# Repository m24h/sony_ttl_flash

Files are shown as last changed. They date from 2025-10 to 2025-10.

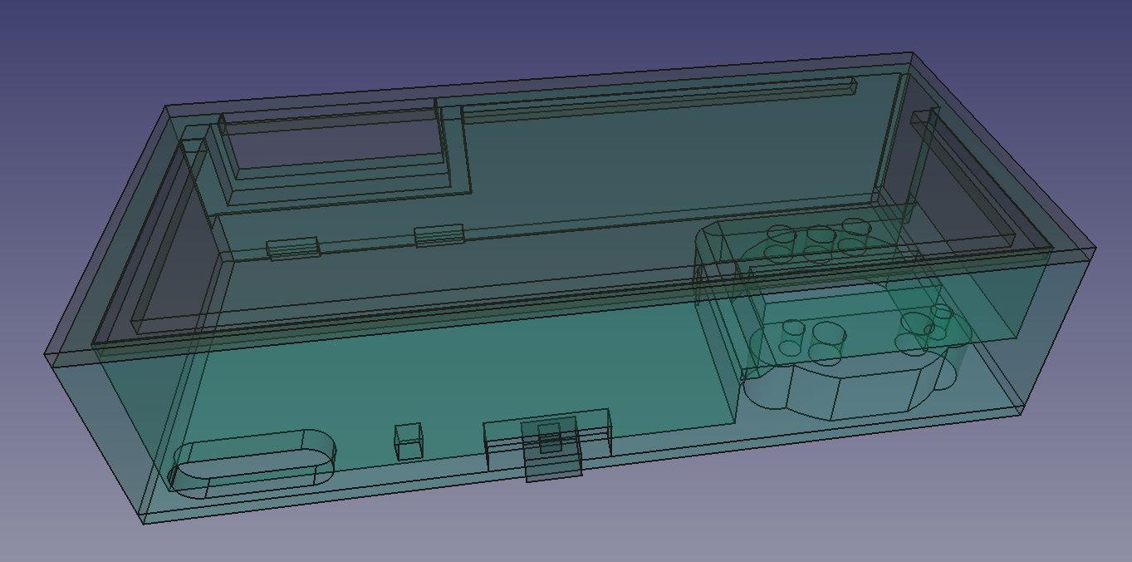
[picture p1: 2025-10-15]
parts/shell.png

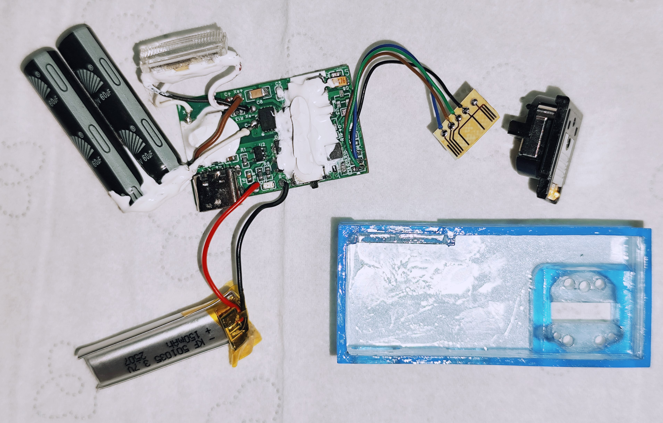
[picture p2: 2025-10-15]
practice/connection.jpg

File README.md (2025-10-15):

# sony_ttl_flash

A small Sony P-TTL flash

## Sony P-TTL and some details

Based on the discussion at [Discovering the flash protocol (long)](https://www.dyxum.com/dforum/topic8297.html), with some of my own research added, the camera will interact with the flash, reading the maximum flash power of the flash, indicating to the flash to fire at an appropriate energy. For specifics, see flash_sony.h.
FEL is not supported because I don't think it's needed, but if support is desired, flash.c needs to be modified, changing FLASH_SONY_READ_FEATURE_DEF to FLASH_SONY_READ_FEATURE_DEF | FLASH_SONY_READ_FEATURE_NEW, and it will increase the workload of communication (which can still be easily handled).
During macro photography, the camera's pre-flash seems too strong, which can lead to an underestimation of the flash level. Therefore, some corrections were made algorithmically, see FLASH_LOW_FLASH_ENHANCE in flash.h/flash.c.
The compiler is SDCC v4.5, and the compiled binary file is main.bin, designed based on STC8H1K08 (base on 8051, but MCU needs to support rising edge triggered interrupts), and the burning details refer to readme.txt and STC8H1K08.cfg.
The flash time of the level (flash_time_of_level in main.c) is specially calibrated for my actual xenon tube and capacitor, and may require recalibration on other tubes.
It's tested only on my A7CR camera.

## Pulseview

A sony flash protocol plug-in for pulseview is provided in directory pulseview. 

## Note and Issues

Frequent use of maximum power flash may damage IGBTs that do not have perfect cooling design.
The design is too small - but it's exactly what I need - the light will be blocked by a large lens, so I recommend using a small lens with a longer focal length.
The power switch is designed too small, making it inconvenient to operate. If necessary and there is extra space inside the casing, you could consider wiring it to a larger switch.

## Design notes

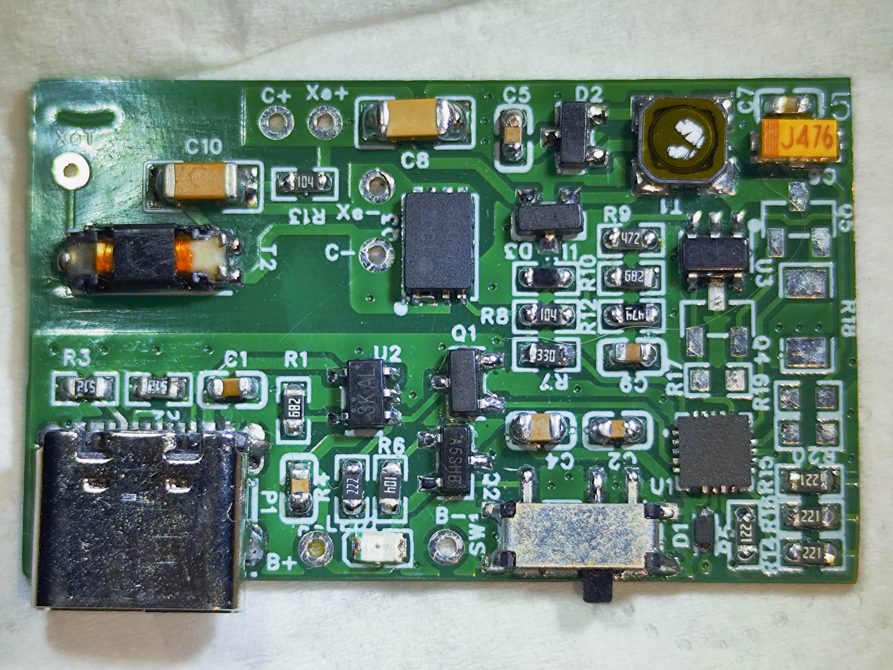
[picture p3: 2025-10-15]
practice/pcb_not_the_final.jpg

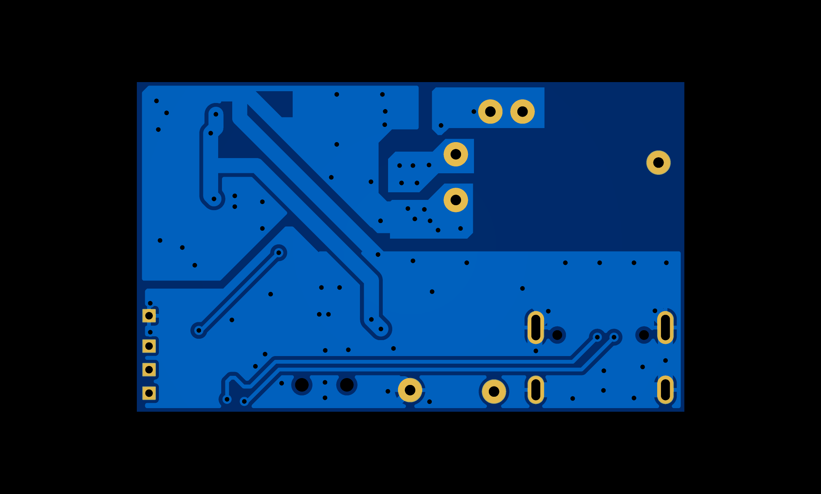
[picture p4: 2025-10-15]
circuit/pcb_bottom.png

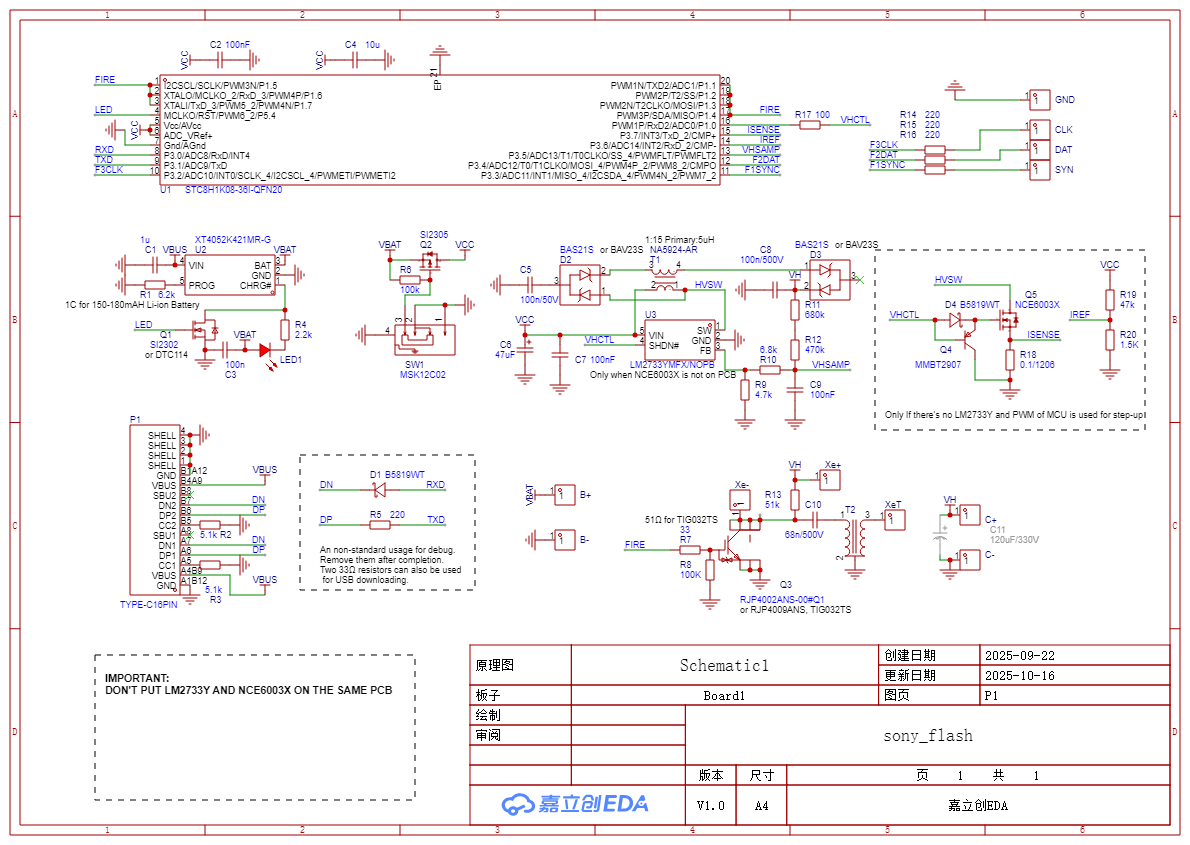
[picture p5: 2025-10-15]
circuit/sch.png

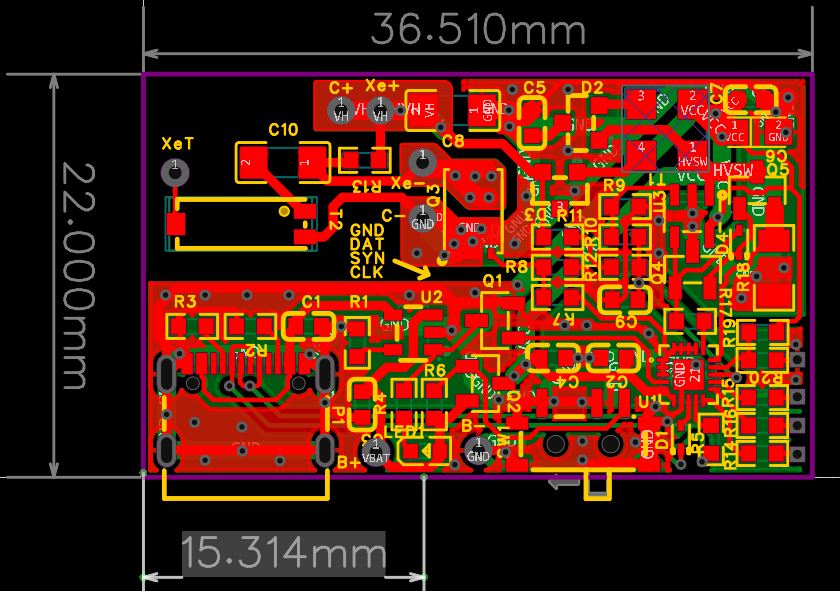
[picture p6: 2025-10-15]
circuit/pcb_size.png

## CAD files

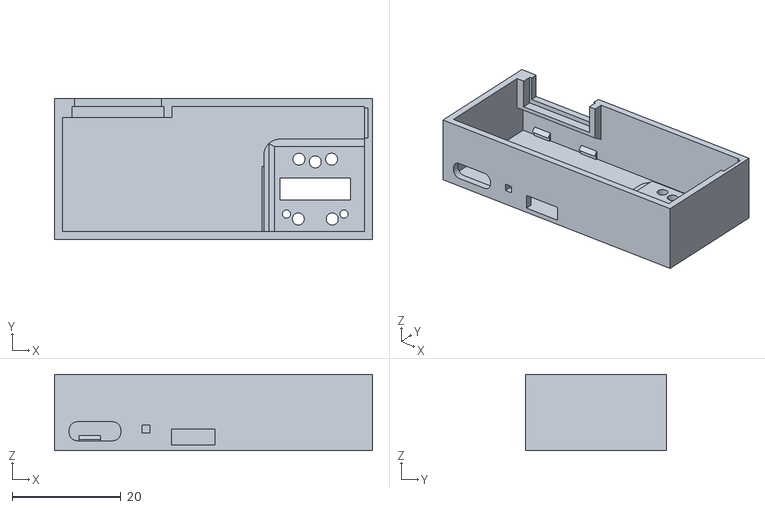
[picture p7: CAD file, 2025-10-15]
parts/shell-Body.stl
58.5 x 26.0 x 14.0

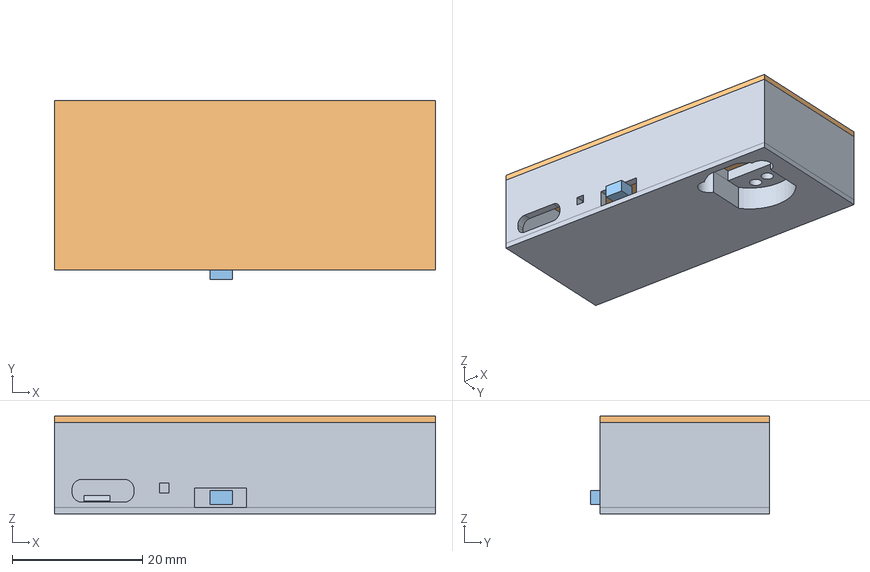
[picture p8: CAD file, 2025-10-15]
parts/shell.FCStd
58.5 x 27.5 x 15.0 mm
lid
knob

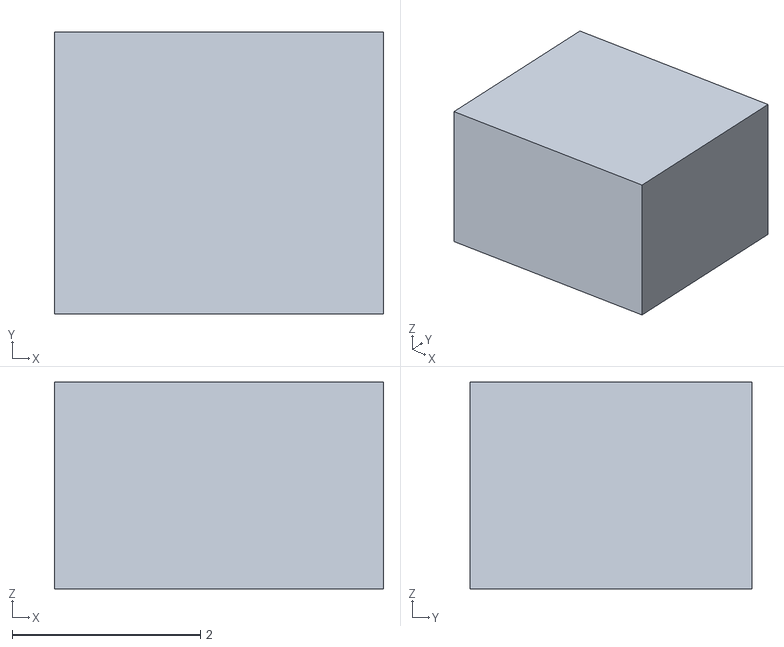
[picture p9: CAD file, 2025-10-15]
parts/shell-knob.stl
3.50 x 3.00 x 2.20

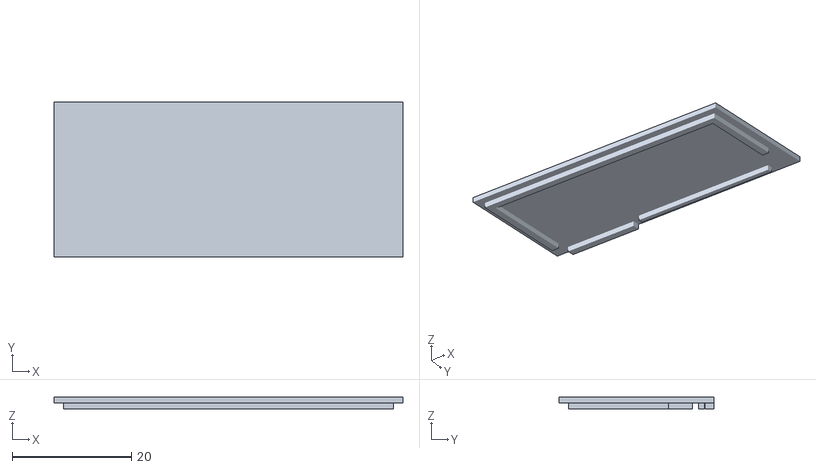
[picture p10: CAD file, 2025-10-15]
parts/shell-lid.stl
58.5 x 26.0 x 2.00

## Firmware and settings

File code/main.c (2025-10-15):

#include "main.h"

#include "stc/mem.h"
#include "stc/pio.h"
#include "stc/tmr.h"
#include "stc/sys.h"
#include "stc/ser.h"
#include "stc/adc.h"
#include "flash.h"

/*
this is a small flash with small Xenon tube and capacitor (GN6), 
so uses nearly a 1/4 full power (at flash_time_of_level[0]) as base/pre-flash power.
this table needs to be recalibrated after changing the Xenon tube and capacitor models. 
*/
const uint16_t flash_time_of_level[64] = {
52,61,72,87,104,126,151,183,
318,318,318,318,318,318,318,318,
318,318,318,318,318,318,318,318,
318,318,318,318,318,318,318,318,
12,12,12,12,12,12,13,14,
14,14,14,15,15,15,15,16,
17,18,19,19,20,21,21,22,
24,26,28,30,33,37,41,47
};


uint16_t volt_vdd_mv = 4000;
uint16_t volt_high = 0;

// ADC ref voltage, normally 1190mV
static uint16_t adc_ref=1190;

static __bit HV_disable = 0;
static __bit HV_on = 0;

#pragma save
#pragma disable_warning 126 // unreachable code by some setup macros
static void setup(void)
{
    sys_wdt_enable(1000, 0);
            
    // set ports (pins connected to camera are excluded)
    pio_disable_all();
    pio_reset(0);   // not to use reset pin
    pio_mclk(0, 0); // not to output sys clock
    VHSAMP=0;  pio_config(pio_pnn(VHSAMP), PIO_ANALOG); // VHSAMP
    RXD=1;     pio_config(pio_pnn(RXD), PIO_BIDIR | PIO_SCHMITT); 
    TXD=1;     pio_config(pio_pnn(TXD), PIO_BIDIR | PIO_SCHMITT); 
    LED=0;     pio_config(pio_pnn(LED), PIO_OUTPUT);
    P11=0;     pio_config(pio_pnn(P11), PIO_OUTPUT | PIO_STRONG | PIO_FAST); // to drive IGBT
    P12=0;     pio_config(pio_pnn(P12), PIO_OUTPUT | PIO_STRONG | PIO_FAST); // to drive IGBT
    P13=0;     pio_config(pio_pnn(P13), PIO_OUTPUT | PIO_STRONG | PIO_FAST); // to drive IGBT
    P14=0;     pio_config(pio_pnn(P14), PIO_OUTPUT | PIO_STRONG | PIO_FAST); // to drive IGBT
    P15=0;     pio_config(pio_pnn(P15), PIO_OUTPUT | PIO_STRONG | PIO_FAST); // to drive IGBT
    P16=0;     pio_config(pio_pnn(P16), PIO_OUTPUT | PIO_STRONG | PIO_FAST); // to drive IGBT
    P17=0;     pio_config(pio_pnn(P17), PIO_OUTPUT | PIO_STRONG | PIO_FAST); // to drive IGBT
    VHCTL=0;   pio_config(pio_pnn(VHCTL), PIO_OUTPUT | PIO_STRONG | PIO_FAST); // maybe needs to drive MOS

    // serial port 1 as debug port
    ser1_setup(BAUDRATE, 1, SER1_P30P31, 0); // use timer 1 to drive it, not to use intr.
    debug(1, "Starting\n");
        
    // LVD level
    sys_lvd_setup(3000, 0, 0);
    
    // timer 2 ticks every 10ms, started, will raise intr.
    tmr2_setup_reload24(100, 1, 1, 0, 0);

    // setup ADC
    adc_setup(ADC_RATE, 0, 0); // not to raise intr.
    debug(1, "ADC Rate = %u kHz\n", (uint16_t)(adc_real_speed(ADC_RATE)/1000));
#ifdef ADC_REF_MV
    adc_ref = ADC_REF_MV;
#else
    adc_ref = adc_ref_mv();
    if (adc_ref<1000 || adc_ref>1300) adc_ref=1190; // maybe VRef is not writen into ROM, so use the default
#endif
    debug(1, "ADC Ref = %u mV\n", adc_ref);
    
#ifdef USE_PWM_STEP_UP
    CMPCR2 = DISFLT; // not inv., no filter
    CMPEXCFG = 0;
    CMPCR1 = CMPEN | 0x04; // enable and use P36 as negative input
    PWMA_CCER1 = 0x00; // disable output for setting up
    PWMA_CR1 = 0x80; // ARR pre-load, stopped for setting up
    PWMA_CR2 = 0; 
    PWMA_RCR = 0;
    PWMA_IER = 0; // no intr. used
    PWMA_CCMR1 = 0x68; // PWM mode1, CCR pre-load
#if FOSC<20000000
#error PWM algorithm only work in at least 20MHz
#endif
    PWMA_PSCRH = 0;  // no clock pre-scale 
    PWMA_PSCRL = 0;
    PWMA_CNTRH = 0;
    PWMA_CNTRL = 0;
    PWMA_CCR1H = (uint16_t)(1.5476e-6*FOSC)>>8 ; // 4.2V, 5uH, 1.5476us -> 1.3A
    PWMA_CCR1L = (uint8_t)(uint16_t)(1.5476e-6*FOSC);
    PWMA_ARRH = 0xFF; // initialized maximum period
    PWMA_ARRL = 0xFF;
    PWMA_BKR = 0x3C; // MOE=0, AOE=0, BKP=1, BKE=1, OSSR=1, OSSI=1
    PWMA_OISR = 0; // idle state: OC1=0
    PWMA_PS = 0; // PWM1P in P10 
    PWMA_ETRPS = 0x07; // use comparator output as BRK
    PWMA_IOAUX = 0; 
    PWMA_ENO = 0x01; // enable PWM1P output
    PWMA_CCER1 = 0x01; // enable CC1P
    PWMA_CR1 |= 0x01; // start 
#endif    
}
#pragma restore

// timer 2 as system tick
static __data volatile uint16_t tick_10ms_isr = 0;
void tmr2_isr(void) __interrupt (TMR2_VECTOR) __naked
{
    // _tick_10ms_isr++
    __asm
    push    acc
    push    psw
    inc _tick_10ms_isr
    clr a
    cjne a, _tick_10ms_isr, 00010$
    inc (_tick_10ms_isr + 1)
00010$:
    pop psw
    pop acc
    reti
    __endasm;
}

uint16_t main_tick_get(void) __naked
{
    __asm
    anl _IE2, #(~ET2)
    nop
    nop
    mov dpl, (_tick_10ms_isr)
    mov dph, (_tick_10ms_isr+1)
    orl _IE2, #(ET2)
    ret
    __endasm;
}

static void shutdown(void)
{
    FLASH_STOP;
    HV_on = 0; // turn off high voltage
#ifdef USE_PWM_STEP_UP
    PWMA_BKR &= ~0xC0; // MOE=AOE=0 
#else
    VHCTL = 0;  
#endif    
    
    LED=0;
    sys_delay_ms(50);
}

// main entry
void main(void)
{
    
    EA = 0;
    nop();
    nop();
    mem_xram_enable();
    setup();
    flash_setup();
    EA = 1;
    
    // main loop
    while(1) {
        // feed the dog
        sys_wdt_clear();
        
        static uint16_t loops=0;
        ++loops;

        // power control
        if (PCON & LVDF || volt_vdd_mv<3200 || HV_disable) {
            HV_on = 0;
        } else if (volt_high<(uint16_t)(VH_DEST)-5) {
            HV_on = 1;
        } else if (volt_high>(uint16_t)(VH_DEST)+5) {
            HV_on = 0;
        }
        
#ifdef USE_PWM_STEP_UP
        if (HV_on) PWMA_BKR |= 0xC0; // MOE=AOE=1
        else PWMA_BKR &= ~0xC0; // MOE=AOE=0
#else
        VHCTL = HV_on;  
#endif    

        //To speed up the cycle turnaround, the tasks are spreaded using task number, which should be at 1-255
        static __data uint8_t taskno = 0;
        ++taskno;
        if (taskno == 1) { // get device voltages
            uint16_t t16 = adc_get(ADC_VREF_CH);
            t16 = adc_get(ADC_VREF_CH); // double get to avoid cross-interference
            if (t16<=4096) t16 = adc_get(ADC_VREF_CH);
            if (t16<=256) continue; // sometimes get 0, seems to be the "zero value" bug of STC ADC, many have encountered it too
            // adc_value/65536*Vdd = adc_ref
            // Vdd = adc_ref * 65536 / adc_value
            t16 = (uint16_t)((((uint32_t)adc_ref<<16)+(t16>>1))/t16);
            t16 = ((volt_vdd_mv<<1)+volt_vdd_mv+t16+2)>>2; // a simple filter
            EA = 0; // guarantee actomic data
            nop();
            nop();
            volt_vdd_mv=t16;
            EA = 1;
        } else if (taskno == 2) { // get high voltage
            uint16_t t16 = adc_get(ADC_VHSAMP_CH);
            t16 = adc_get(ADC_VHSAMP_CH); // double get to avoid cross-interference
            if (t16<=4096) t16 = adc_get(ADC_VHSAMP_CH);
            if (t16<=256) continue; // sometimes get 0 or noises, seems to be the "zero value" bug of STC ADC, many have encountered it too
            // adc_value/65536*volt_vdd_mv/1000 = volt_high*VH_RATIO+VH_BIAS
            // volt_high = (adc_value/65536*volt_vdd_mv/1000 - VH_BIAS)/VH_RATIO
            // volt_high = (1049*(adc_value/64)*volt_vdd_mv/65536 - VH_BIAS*16384)*(4/VH_RATIO)/65536
            t16 = (1049UL*volt_vdd_mv*(t16>>6)+32768)>>16;
            t16 = t16>(uint32_t)(VH_BIAS*16384) ? ((t16-(uint32_t)(VH_BIAS*16384))*(uint32_t)(4/VH_RATIO)+32768)>>16 : 0;
            t16 = ((volt_high<<1)+volt_high+t16+2)>>2; // a simple filter
            EA = 0; // guarantee actomic data
            nop();
            nop();
            volt_high = t16;
            EA = 1;
#ifdef USE_PWM_STEP_UP
            if (volt_high<=2) {
                PWMA_ARRH = 0xFF;
                PWMA_ARRL = 0xFF;            
            } else {
                uint16_t toff=(uint16_t)(0.08125*0.00128*FOSC)/(volt_high-2)+(uint16_t)(1.5476e-6*FOSC)+2; // 1.3/(15+1)=81.25mA, 5*(15+1)^2=1.28mH
                PWMA_ARRH = toff>>8;
                PWMA_ARRL = (uint8_t)toff;
            }
#endif
        } else if (taskno == 3) { // show LED
            if (volt_high<(uint16_t)(VH_LEAST)) {
                flash_can_fire = 0;
                if (HV_on) {
                    LED = (uint8_t)main_tick_get() & 0x10;
                } else {
                    LED = 1;
                }
            } else {
            	flash_can_fire = 1;
                LED = 1;
            } 
        } else if (taskno == 4) {
            // incoming message (1 byte only) from default serial port
            switch ((unsigned char)tolower(getchar())) {
                case 'b': printf("SP = %x, ticks = %u, loops=%u\n", SP, main_tick_get(), loops);
                          break;
                case 'd': shutdown();
                          pio_disable_all(); 
                          sys_boot_ISP();
                          break;
                case 'r': shutdown();
                          pio_disable_all();
                          sys_boot();
                          break;
                case 'a': printf("VH = %u, VDD = %u mV, VH = %u V\n", HV_on, volt_vdd_mv, volt_high);
                          break;
                case 'p': printf("VH = %u, LVD=%u, LED = %u\n", HV_on, (PCON & LVDF)?1:0, LED);
                          printf("F1SYNC = %u, F2DAT = %u, F3CLK = %u\n", FLASH_F1SYNC, FLASH_F2DAT, FLASH_F3CLK);
                          break;
                case 'c': HV_on = 0;
                          HV_disable = 1;
                          sys_delay_ms(1);
                          printf("VH = %u, VDD = %u mV, VH = %u V\n", HV_on, volt_vdd_mv, volt_high);
                          break;
                case 'x': HV_on = 0;
                          HV_disable = 0;
                          sys_delay_ms(1);
                          printf("VH = %u, VDD = %u mV, VH = %u V\n", HV_on, volt_vdd_mv, volt_high);
                          break;
                case 'f': FLASH_START;
                          sys_delay_us(30);
                          FLASH_STOP;
                          sys_delay_ms(20);
                          FLASH_START;
                          sys_delay_us(100);
                          FLASH_STOP;
                          break;
                case 's': printf("Sony read : ");
                		  for (uint8_t i=0; i<flash_data.rlen; i++) printf("%x ", flash_data.rbytes[i]);
                		  printf("\nSony write : ");
                		  for (uint8_t i=0; i<flash_data.wlen; i++) printf("%x ", flash_data.wbytes[i]);
                		  printf("\nPower pre=%d formal=%d", flash_power_pre, flash_power_formal);
                          printf("\nActual pre=%d formal=%d\n", flash_power_pre_act, flash_power_formal_act);
                          break;
                case 'm': static int8_t power=-15;
                          power++;
                          if (power>FLASH_LEVEL_FULL) power=-12;
                          flash_data.read.mode &= ~FLASH_SONY_READ_MODE_CONTROLLED; // manual mode
                          flash_data.read.power = ((FLASH_POWER_LEVEL_MAX-power)<<2)+15;
                          printf("Manual mode, power=%d\n", power);
						  break;    
                case '?': printf("bdrapcxfsm\n");
                          break;
            } 
        }  else taskno = 0;
    }
} 

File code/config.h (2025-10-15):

// lib config, do not change these if hardware is not changed
#define MCU_STC8H1K08
#define FOSC 22118400

// ports config, do not change these if hardware is not changed
#define VHCTL  P10
#define LED    P54
#define RXD    P30
#define TXD    P31
#define VHSAMP P35
#define ADC_VHSAMP_CH 13 // ADC channel

// flash config
#define FLASH_F1SYNC    P33
#define FLASH_F2DAT     P34
#define FLASH_F3CLK     P32

#define FLASH_LEVEL_FULL 8 // GN6 
#define FLASH_LOW_FLASH_ENHANCE
#define FLASH_START __asm orl P1, #0xfe __endasm
#define FLASH_STOP  __asm anl P1, #0x01 __endasm

// main config
#define DEBUG       2       // debug level, 0 means no debug
#define BAUDRATE    9600

/*
V_sample = V_high * VH_RATIO + VH_BIAS, if VHCTL==1
*/
#define VH_RATIO     ((6.8+4.7)/(680+470+6.8+4.7))
#define VH_BIAS      0
#define VH_LEAST     280     // 250V is the lowest fire voltage, but for P-TTL (double flash), 280V seems to be more stable
#define VH_DEST      300
#define ADC_RATE     100000  // 10us each time
#define ADC_REF_MV   1190

//#define USE_PWM_STEP_UP // IMPORTANT: it's never tested, and LM2733Y must not be on the PCB
